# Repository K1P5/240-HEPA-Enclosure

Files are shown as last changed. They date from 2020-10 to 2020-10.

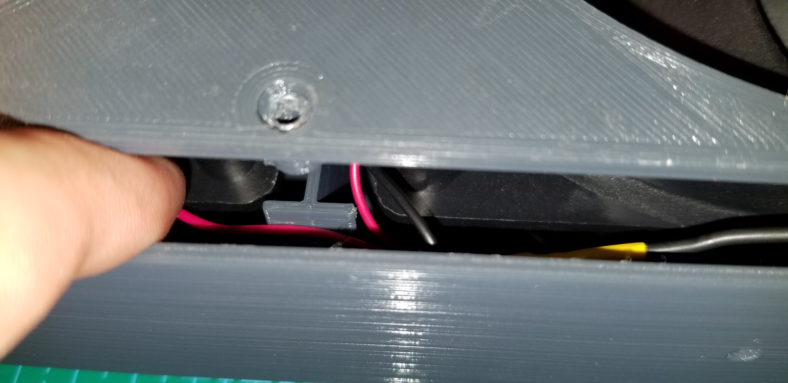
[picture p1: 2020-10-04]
Assembly reference images/20200915_191129.jpg

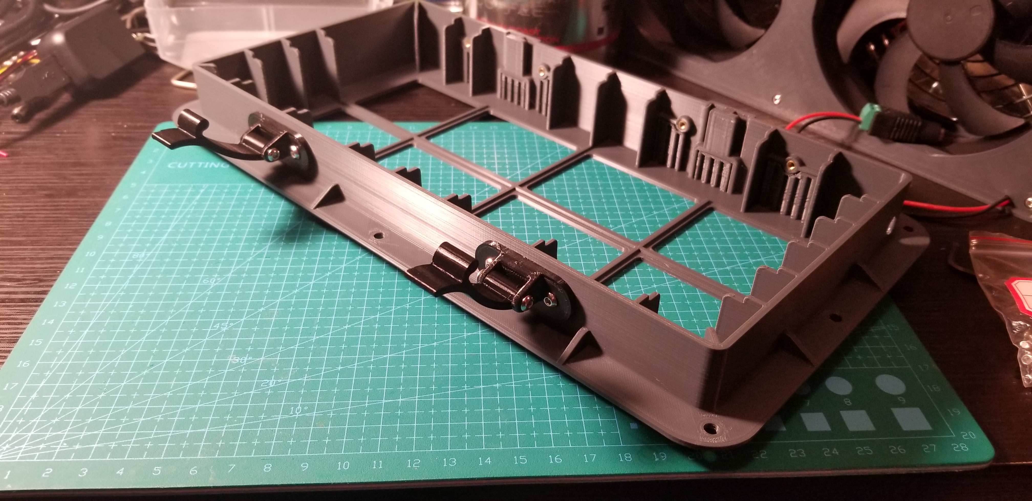
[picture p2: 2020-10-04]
Assembly reference images/20200921_191919.jpg

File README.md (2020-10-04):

# 240-HEPA-Enclosure
Dual 120mm panel mount HEPA filter enclosure. Used with low cost generic molded HEPA filters (and carbon pre-filter pads). 

Example of compatible filters:

[Compatible_Filter](https://www.amazon.com/Wolf-Filter-Allergen-Compatible-HAPF300AH-U4R/dp/B07GVC9MQW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)

[Additional_Vendor](https://www.amazon.com/Colorfullfe-Performance-Replacement-HAPF300AP-U4-Filters/dp/B07W8SXK4B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)

This is a panel-mount style frame that houses a generic, affordable HEPA filter and charcoal pre-filter (example of compatible unit shown within gallery). The frame/enclosure contains mounting positions for two 120mm DC fans, wired in parallel or series, and allows for a range of configurations based on cost and need. I originally designed this to solve a cat problem. One of two is very picky about the lingering odor within the litter box, regardless of cleaning schedule. After a series of litter box upscaling projects (40 gallon bin, magnetic swing door) I finally turned my attention to the odor issue. This HEPA enclosure performs an effective job of turning over the internal volume of the container and now I finally have a satisfied animal. I am currently preparing a second enclosure to test as a 3D Printer Chamber Filter. Use cases will vary. 

Misc. Notes:

The main components are relatively large in size and can be printed on a 330mm x 230mm build plate. PLA has proven to work well for the large parts, PETG for the hinge and latch components.

I use generic 18-8 SS M3 hardware all around as that is what I keep on hand.

Most generic barrel plug panel mount style connectors are compatible with the enclosure.

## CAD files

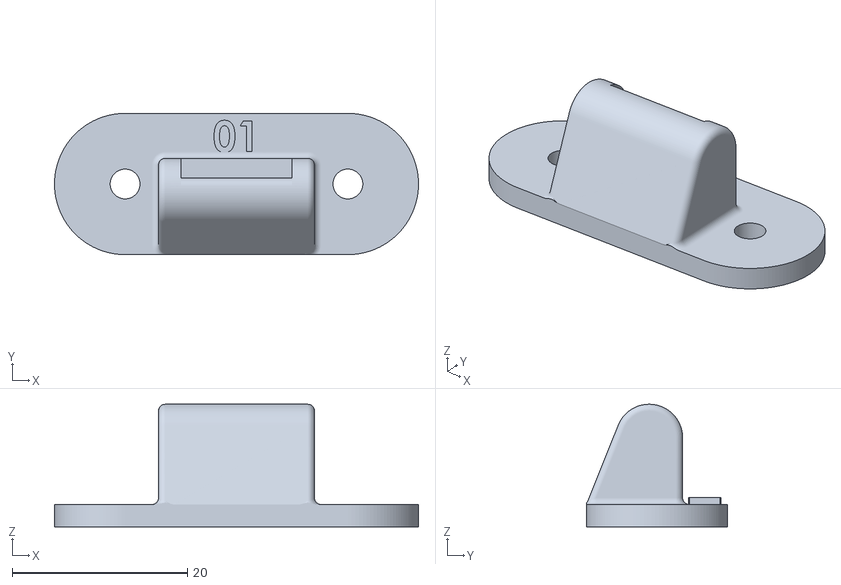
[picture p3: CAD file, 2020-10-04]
STL Files/LATCH B 01.STL
41.5 x 16.1 x 14.0

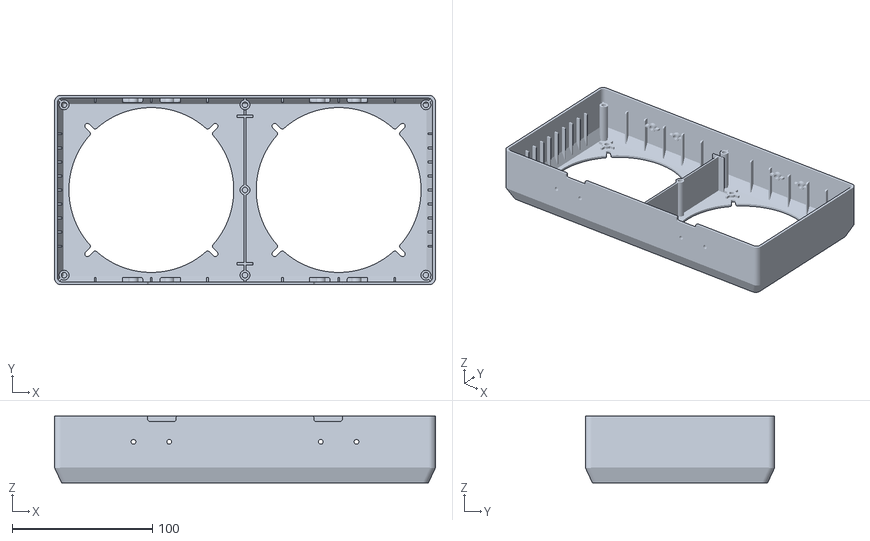
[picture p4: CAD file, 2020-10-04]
STL Files/FAN SHROUD 00.STL
271.3 x 134.9 x 47.6

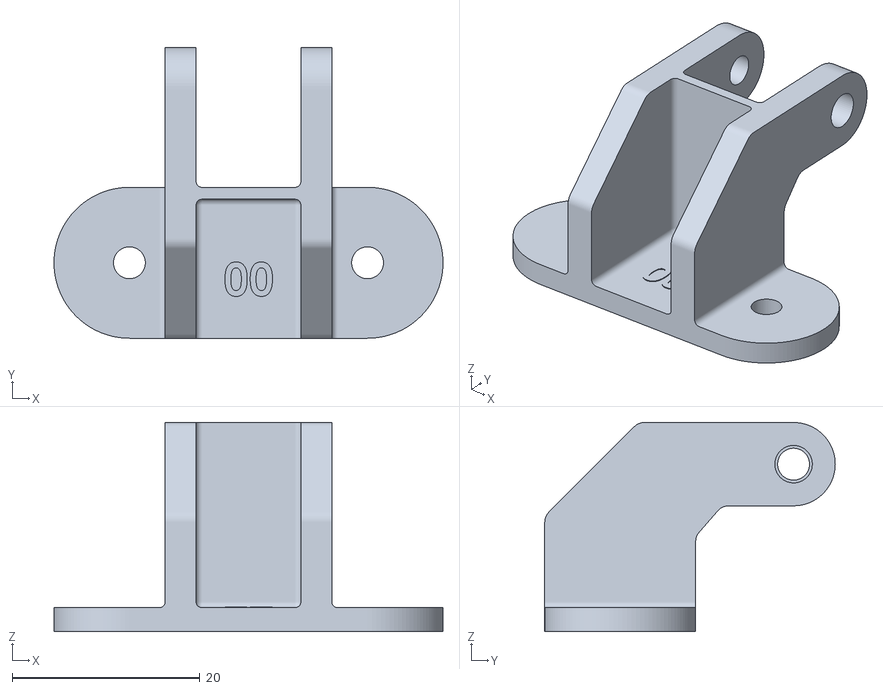
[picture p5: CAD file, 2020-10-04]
STL Files/HINGE B 00.STL
41.5 x 31.0 x 22.3

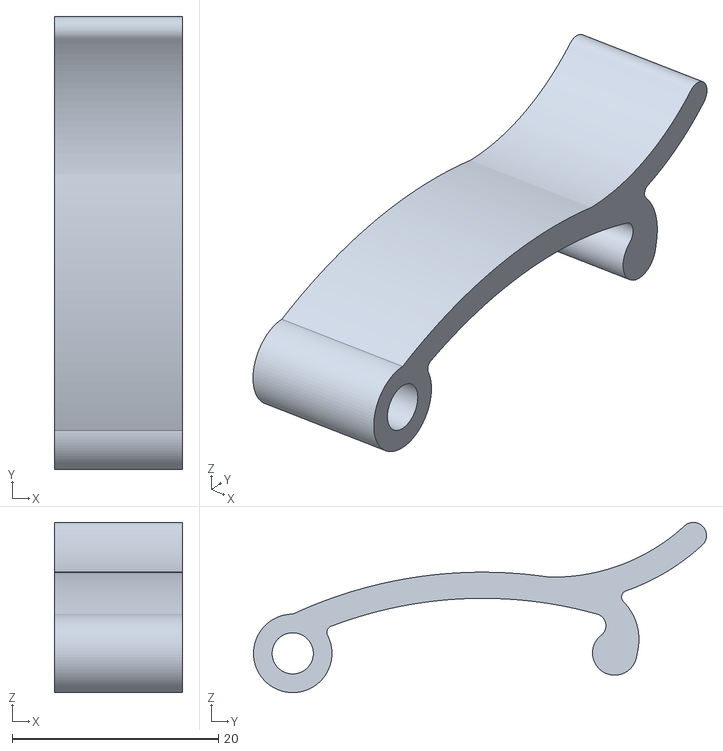
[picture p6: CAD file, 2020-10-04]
STL Files/LATCH ARM 00.STL
12.4 x 44.0 x 16.5

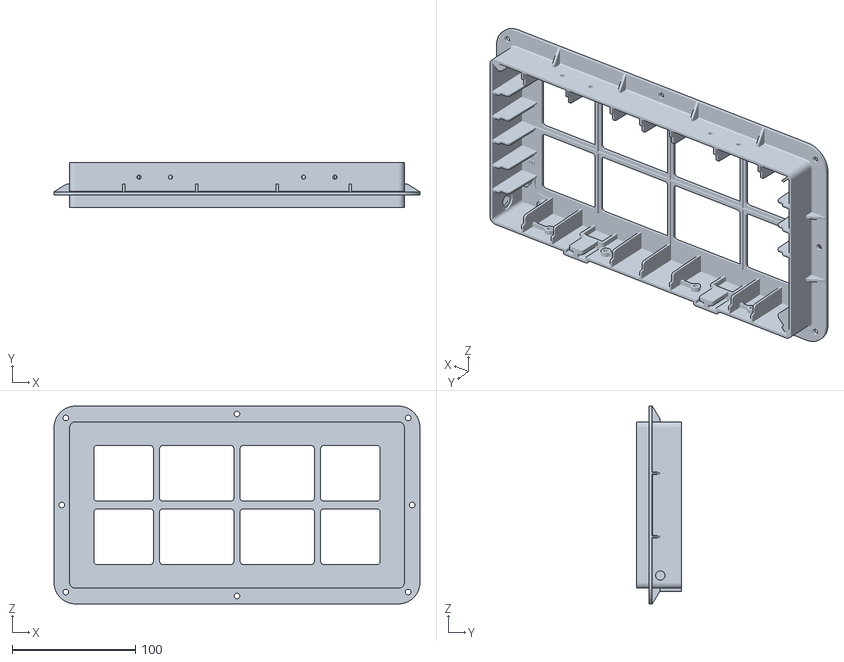
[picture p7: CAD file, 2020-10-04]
STL Files/FILTER BASE 00.STL
296.7 x 36.4 x 160.3

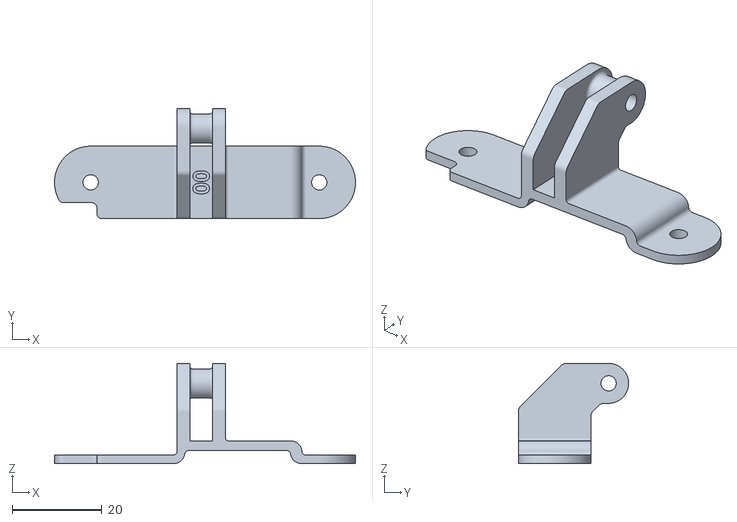
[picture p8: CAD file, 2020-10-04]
STL Files/HINGE A 00.STL
66.9 x 24.5 x 22.3

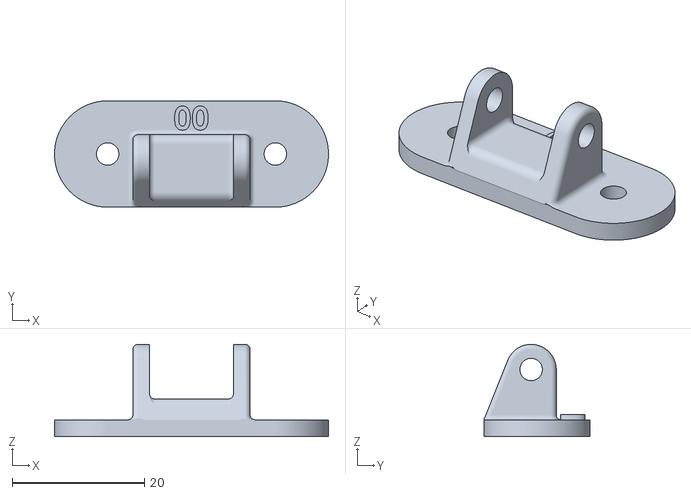
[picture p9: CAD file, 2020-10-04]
STL Files/LATCH A 00.STL
41.5 x 16.1 x 14.0

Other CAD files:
STL Files/HINGE A1 00.STL

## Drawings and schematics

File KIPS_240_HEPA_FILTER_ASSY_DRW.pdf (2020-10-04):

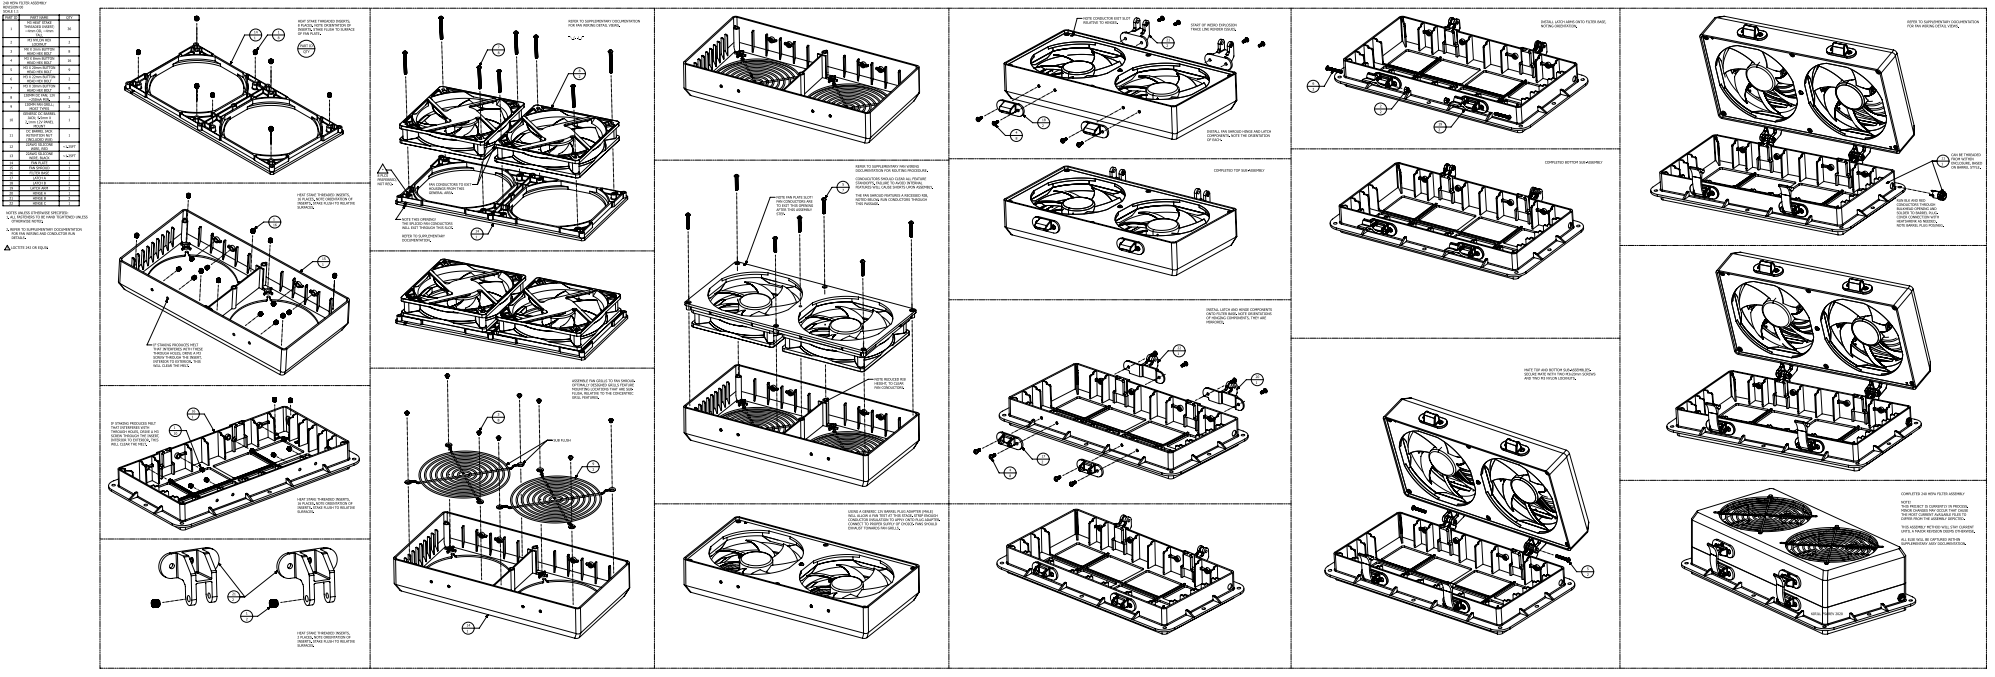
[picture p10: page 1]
PART ID; PART NAME; QTY 1; M3 HEAT STAKE THREADED INSERT; ~4mm OD, ~4mm; HEAD HEX BOLT; 22AWG SILICONE; WIRE, RED; WIRE, BLACK; FAN PLATE; FAN SHROUD; FILTER BASE; LATCH; LATCH ARM; HINGE A; HINGE B; HINGE C; HEPA; FILTER ASSEMBLY; REVISION 00 SCALE 1:1; 1. ALL; FASTENERS TO BE; HAND TIGHTENED UNLESS; FOR; FAN WIRING AND CONDUCTOR RUN; DETAILS. * LOCTITE 242 OR; EQUIV.; INSERTS. STAKE FLUSH; TO SURFACE; FAN PLATE.; COMPLETED 240; INSERTS. STAKE; FLUSH TO RELATIVE; QTY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

NOTE CONDUCTOR EXIT SLOT

HEAT STAKE THREADED INSERTS,
8 PLACES. NOTE ORIENTATION OF

REFER TO SUPPLEMENTARY DOCUMENTATION
FOR FAN WIRING DETAIL VIEWS.

INSTALL LATCH ARMS ONTO FILTER BASE,
NOTING ORIENTATION.

START OF WEIRD EXPLOSION
TRACE LINE RENDER ISSUES.

TALL
M3 NYLON HEX
LOCKNUT
MX X 3mm BUTTON
HEAD HEX BOLT
M3 X 8mm BUTTON

M3 X 20mm BUTTON
M3 X 22mm BUTTON
M3 X 30mm BUTTON
120MM DC FAN; 12V
~250mA MIN.
120MM FAN GRILL;
MOST TYPES
GENERIC DC BARREL
JACK; 5.5mm X
2.1mm 12V PANEL
MOUNT
DC BARREL JACK
RETENTION NUT
(INCLUDED W/8)

INSTALL FAN SHROUD HINGE AND LATCH
COMPONENTS. NOTE THE ORIENTATION
OF EACH.

CAN BE THREADED
FROM WITHIN
ENCLOSURE, BASED
ON BARREL STYLE.

COMPLETED BOTTOM SUB-ASSEMBLY

REFER TO SUPPLEMENTARY FAN WIRING
DOCUMENTATION FOR ROUTING PROCEDURE.

COMPLETED TOP SUB-ASSEMBLY

CONDUCUTORS SHOULD CLEAR ALL FEATURE
STANDOFFS. FAILURE TO AVOID INTERNAL
FEATURES WILL CAUSE SHORTS UPON ASSEMBLY.

FAN CONDUCTORS TO EXIT
HOUSINGS FROM THIS
GENERAL AREA.

16 PLACES. NOTE ORIENTATION OF
SURFACES.

THE FAN SHROUD FEATURES A RECESSED RIB,
NOTED BELOW. RUN CONDUCTORS THROUGH
THIS PASSAGE.

NOTE FAN PLATE SLOT!
FAN CONDUCTORS ARE
TO EXIT THIS OPENING
AFTER THIS ASSEMBLY
STEP.

RUN BLK AND RED
CONDUCTORS THROUGH
BULKHEAD OPENING AND
SOLDER TO BARREL PLUG.
COVER CONNECTION WITH
HEATSHRINK AS NEEDED.
NOTE BARREL PLUG POS/NEG.

NOTES UNLESS OTHERWISE SPECIFIED:
OTHERWISE NOTED.

NOTE THIS OPENING!
THE SPLICED FAN CONDUCTORS
WILL EXIT THROUGH THIS SLOT.

2. REFER TO SUPPLEMENTARY DOCUMENTATION

REFER TO SUPPLEMENTARY
DOCUMENTATION.

INSTALL LATCH AND HINGE COMPONENTS
ONTO FILTER BASE. NOTE ORIENTATIONS
OF HINGING COMPONENTS, THEY ARE
MIRRORED.

IF STAKING PRODUCES MELT
THAT INTERFERES WITH THESE
THROUGH HOLES, DRIVE A M3
SCREW THROUGH THE INSERT,
INTERIOR TO EXTERIOR. THIS
WILL CLEAR THE MELT.

MATE TOP AND BOTTOM SUB-ASSEMBLIES.
SECURE MATE WITH TWO M3x20mm SCREWS
AND TWO M3 NYLON LOCKNUTS.

NOTE REDUCED RIB
HEIGHT, TO CLEAR
FAN CONDUCTORS.

ASSEMBLE FAN GRILLS TO FAN SHROUD.
OPTIMALLY DESIGNED GRILLS FEATURE
MOUNTING LOCATIONS THAT ARE SUB-
FLUSH, RELATIVE TO THE CONCENTRIC
GRILL FEATURES.

THAT INTERFERES WITH

INSERTS. STAKE FLUSH TO RELATIVE

NOTE!
THIS PROJECT IS CURRENTLY IN PROCESS.
MINOR CHANGES MAY OCCUR THAT CAUSE
THE MOST CURRENT AVAILABLE FILES TO
DIFFER FROM THE ASSEMBLY DEPICTED.

USING A GENERIC 12V BARREL PLUG ADAPTER (MALE)
WILL ALLOW A FAN TEST AT THIS STAGE. STRIP ENOUGH
CONDUCTOR INSULATION TO APPLY ONTO PLUG ADAPTER.
CONNECT TO PROPER SUPPLY OF CHOICE. FANS SHOULD
EXHAUST TOWARDS FAN GRILLS.

THIS ASSEMBLY METHOD WILL STAY CURRENT
UNTIL A MAJOR REVISION DEEMS OTHERWISE.

ALL ELSE WILL BE CAPTURED WITHIN
SUPPLEMENTARY ASSY DOCUMENTATION.

2 PLACES. NOTE ORIENTATION OF

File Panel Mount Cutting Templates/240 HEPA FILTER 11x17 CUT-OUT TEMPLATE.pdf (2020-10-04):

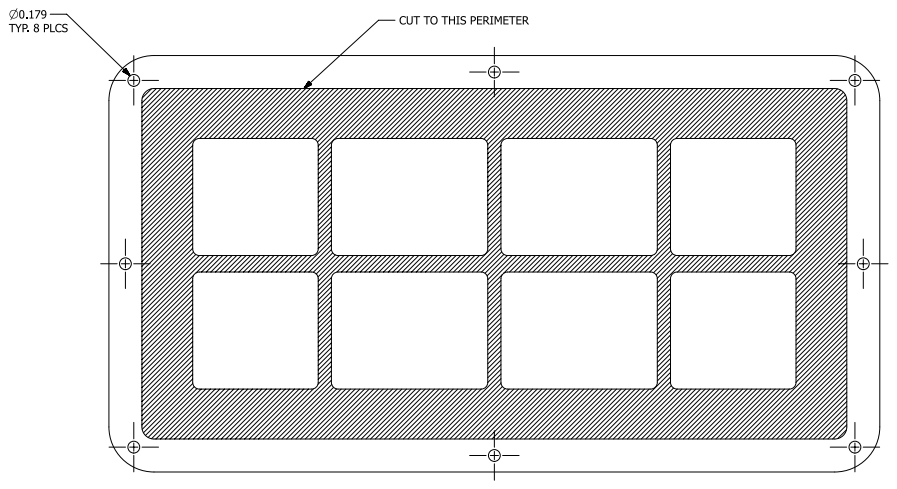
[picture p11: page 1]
TYP. 8 PLCS; CUT TO THIS PERIMETER

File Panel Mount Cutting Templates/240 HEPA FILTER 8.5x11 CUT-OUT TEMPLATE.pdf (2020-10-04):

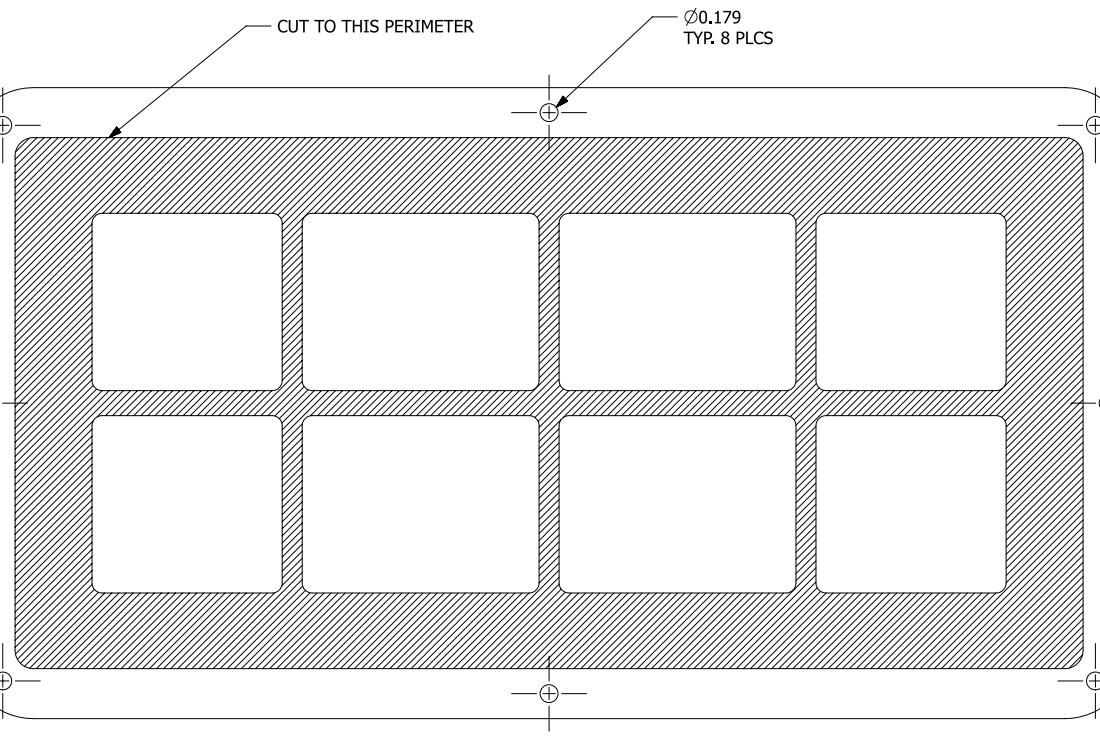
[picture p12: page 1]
⌀0.179 TYP. 8 PLCS

CUT TO THIS PERIMETER

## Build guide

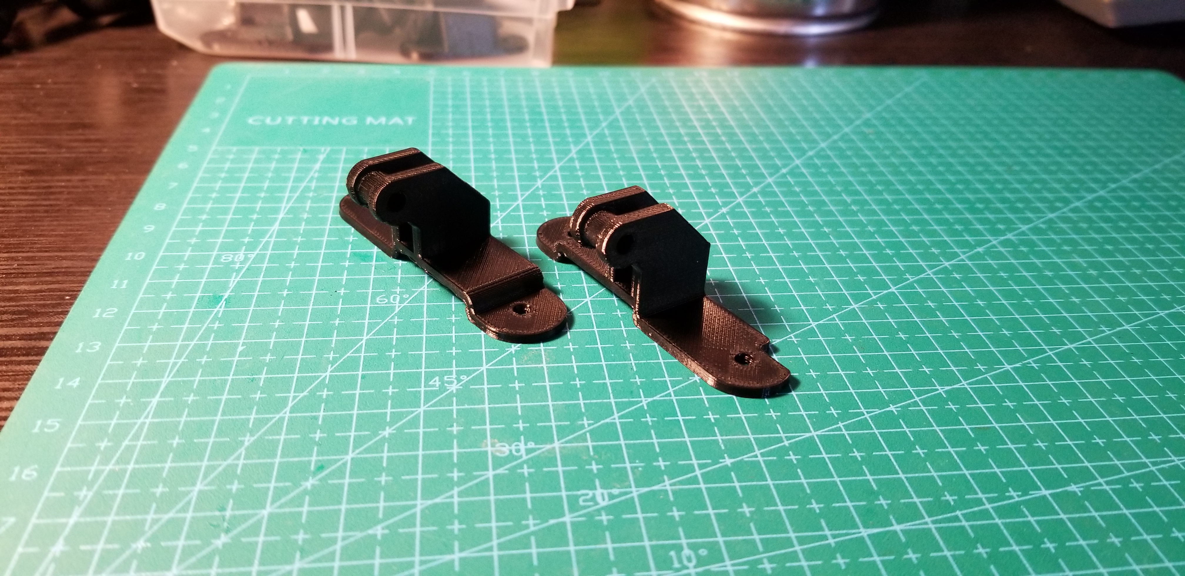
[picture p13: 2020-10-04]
Assembly reference images/20200922_171304.jpg

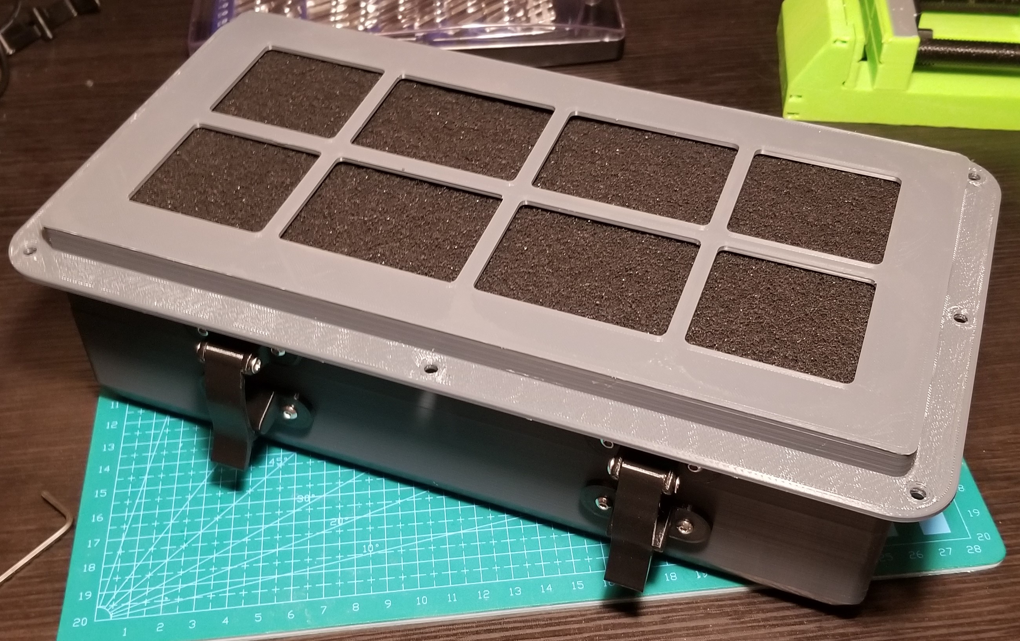
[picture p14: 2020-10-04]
Assembly reference images/20200922_205824.jpg

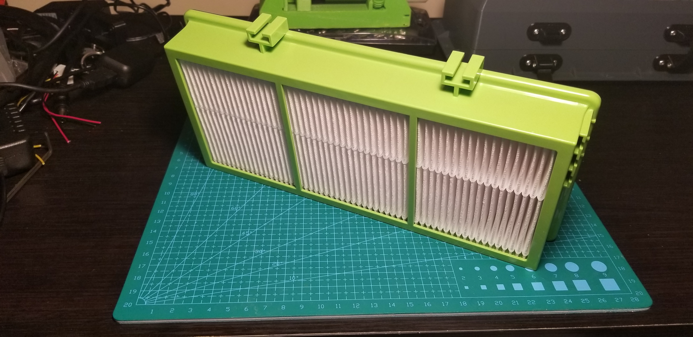
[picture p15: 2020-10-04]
Assembly reference images/20200922_203619.jpg

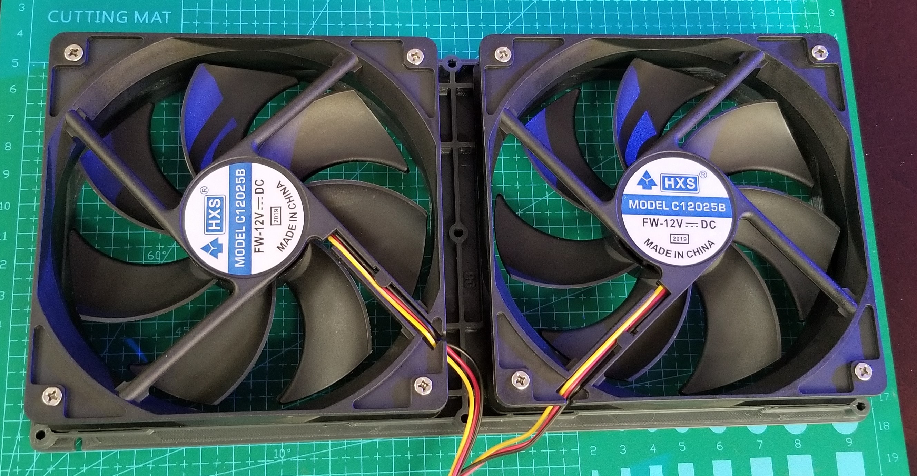
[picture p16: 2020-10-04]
Assembly reference images/20200914_181627.jpg
